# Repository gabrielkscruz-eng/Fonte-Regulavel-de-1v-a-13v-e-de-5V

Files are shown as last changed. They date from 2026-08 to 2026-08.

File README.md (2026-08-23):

# Fonte de Alimentação de Bancada

Projeto de desenvolvimento de **fontes de alimentação para bancada**, realizado no curso de **Engenharia da Computação da Universidade Santa Cecília (UNISANTA)**.

O repositório reúne duas etapas do desenvolvimento:

* **Fonte de alimentação fixa de 5 V**
* **Fonte de alimentação regulável bivolt**

O projeto envolveu o desenvolvimento dos circuitos eletrônicos, criação das placas de circuito impresso, prototipagem, testes e desenvolvimento do encapsulamento da fonte regulável.

---

## Sobre o projeto

Fontes de alimentação são utilizadas para fornecer tensão adequada e estável para circuitos eletrônicos. Em aplicações de bancada, uma fonte regulável permite trabalhar com diferentes níveis de tensão durante testes e desenvolvimento de circuitos.

Neste projeto foram desenvolvidas duas fontes em etapas. A primeira foi uma **fonte fixa de 5 V**, utilizada como uma etapa inicial de desenvolvimento. Posteriormente, foi desenvolvida uma **fonte regulável bivolt**, incorporando uma saída fixa de 5 V e uma saída variável.

O desenvolvimento permitiu aplicar conhecimentos relacionados a **retificação, filtragem, regulagem de tensão, dissipação térmica, proteção de componentes, desenvolvimento de PCB e fabricação do encapsulamento**.

---

# Fonte de 5 V

A primeira etapa do projeto consistiu no desenvolvimento de uma fonte com **saída fixa de 5 V**.

O circuito utiliza o **LM7805** como regulador de tensão e foi desenvolvido utilizando o KiCad.

### Principais características

* Saída regulada de **5 V DC**
* Regulador **LM7805**
* Circuito de retificação
* Filtragem da tensão
* Capacitores para estabilização
* PCB própria

### Fluxo simplificado

```text
Entrada AC
    │
    ▼
Transformação
    │
    ▼
Retificação
    │
    ▼
Filtragem
    │
    ▼
LM7805
    │
    ▼
Saída 5 V DC
```

Os arquivos referentes à fonte fixa estão disponíveis na pasta:

**[`Fonte_5V_Fixa`](./Fonte_5V_Fixa/)**

Nela estão disponíveis os arquivos de projeto do KiCad e os documentos em PDF referentes ao esquemático e à placa.

---

# Fonte Regulável Bivolt

A segunda etapa consistiu no desenvolvimento de uma **fonte de alimentação regulável e bivolt**.

O projeto foi desenvolvido com o objetivo de possuir uma entrada selecionável entre **110 V e 220 V**, uma saída fixa de 5 V e uma saída variável.

O projeto também incluiu o desenvolvimento da PCB, sistema de ventilação e encapsulamento físico.

## Especificações finais

| Característica | Especificação |
| --- | --- |
| Entrada | 110/220 V AC |
| Transformador | 12 V / 3 A |
| Saída fixa | 5 V DC |
| Saída variável | **11 V a 13 V DC** |
| Regulador da saída variável | LM317 |
| Regulador da saída de 5 V | LM7805 |
| Regulador de 12 V | LM7812 |
| Ponte retificadora | KBU808 |
| Potenciômetro | 10 kΩ |
| Dimensão da PCB | 10 × 7,5 cm |
| Dimensão do gabinete | 15 × 11 × 15 cm |
| Material do gabinete | MDF |

A relação de componentes do projeto inclui, entre outros, ponte retificadora KBU808, reguladores LM7805, LM7812 e LM317, diodos 1N4004, capacitores de 4700 µF, capacitores de desacoplamento, resistor de 220 Ω e potenciômetro de 10 kΩ.

---

# Funcionamento

O funcionamento da fonte regulável pode ser dividido em algumas etapas principais:

```text
                 ┌──────────────► LM7805 ───► 5 V DC
                 │
Rede AC          │
  │              │
  ▼              │
Seletor          │
110/220 V        │
  │              │
  ▼              │
Transformador    │
12 V / 3 A       │
  │              │
  ▼              │
KBU808            │
Retificação       │
  │              │
  ▼              │
Filtragem         │
4700 µF           │
  │              │
  ├───────────────┼──────► LM7812 ───► 12 V
  │              │
  │              └──────► LM317 ────► Saída variável
  │                                      │
  ▼                                      ▼
Tensão DC filtrada                    11 V ~ 13 V
```

O transformador reduz a tensão da rede, a ponte KBU808 realiza a retificação e os capacitores fazem a filtragem da tensão. Após essa etapa, os reguladores são responsáveis por gerar as saídas previstas no projeto.

---

# Componentes principais

## Fonte regulável

* Transformador bivolt **12 V / 3 A**
* Ponte retificadora **KBU808**
* **LM7805**
* **LM7812**
* **LM317**
* 3 × diodos **1N4004**
* 2 × capacitores eletrolíticos **4700 µF**
* 2 × capacitores **0,33 µF**
* 3 × capacitores **0,1 µF**
* Resistor **220 Ω**
* Potenciômetro **10 kΩ**
* 6 × conectores borne
* Seletor **110/220 V**
* Chave alavanca
* Fusível
* Conector para cabo de alimentação

---

# Desenvolvimento da PCB

A esquemática e o layout da placa foram desenvolvidos utilizando o **KiCad 7.0**.

A PCB possui dimensões de aproximadamente:

**10 × 7,5 cm**

A fabricação da placa foi realizada por meio de **fresagem em placa de fenolite** nas instalações do **INOVFabLab da Universidade Santa Cecília**.

Os arquivos editáveis do KiCad estão disponíveis diretamente neste repositório, permitindo visualizar e modificar o projeto eletrônico.

### Arquivos disponíveis

```text
Fonte_regulavel/
├── fonte_regulavel.kicad_pro
├── fonte_regulavel.kicad_sch
├── fonte_regulavel.kicad_pcb
├── Esquemática Fonte regulavel.pdf
└── Placa da Fonte Regulavel.pdf
```

---

# Desenvolvimento do encapsulamento

O encapsulamento da fonte regulável foi desenvolvido utilizando o **Autodesk Fusion 360**.

A estrutura foi projetada para acomodar a placa eletrônica e os demais componentes da fonte.

A fabricação foi realizada em **MDF utilizando corte a laser**.

### Dimensões

**15 × 11 × 15 cm**

Foi utilizada uma placa de MDF de 1,3 × 0,9 m para a fabricação do gabinete.

O arquivo do encapsulamento está disponível na pasta:

**[`Gabinete`](./Gabinete/)**

---

# Evolução do projeto

O desenvolvimento da fonte regulável ocorreu a partir da experiência obtida durante a primeira etapa do projeto.

Inicialmente, foi planejada a utilização de duas placas. A placa da entrega parcial possuía saídas fixas de **5 V e 12 V**, sendo a saída de 5 V destinada à carga e a saída de 12 V destinada à ventoinha utilizada para auxiliar no resfriamento do regulador.

Durante a prototipagem foram identificados problemas na placa da entrega parcial. Como consequência, foi decidido integrar os componentes em uma única placa.

Também houve uma alteração no circuito da saída variável. O circuito inicialmente planejado foi substituído pelo **LM317**, devido à praticidade de implementação.

---

# Resultado final

Após a montagem e os testes do protótipo, foram obtidas as seguintes saídas:

### Saída fixa

**5 V DC**

### Saída variável

**11 V a 13 V DC**

A saída variável apresentada neste README corresponde ao **resultado final obtido nos testes do protótipo**.

O relatório acadêmico registra, em sua seção de resultados, uma faixa de 1,10 V a 13 V para o protótipo documentado naquele momento. O valor de **11 V a 13 V** apresentado aqui corresponde ao resultado final considerado para este repositório.

---

# Comparação das duas fontes

| Característica | Fonte 5 V | Fonte Regulável |
| --- | ---: | ---: |
| Saída fixa | 5 V | 5 V |
| Saída variável | Não | 11–13 V |
| Entrada bivolt | Não especificada | 110/220 V |
| LM7805 | Sim | Sim |
| LM7812 | Não | Sim |
| LM317 | Não | Sim |
| PCB | Sim | Sim |
| Encapsulamento | Não | MDF |
| Ventilação | Não | Sim |

---

# Organização do repositório

```text
Fonte-Regulavel-de-1v-a-13v-e-de-5V-main/
│
├── README.md
│
├── Documentação/
│   └── RELATÓRIO FONTE.pdf
│
├── Fonte_5V_Fixa/
│   ├── Esquemática da placa de 5V.pdf
│   ├── Fonte_5v.kicad_pcb
│   ├── Fonte_5v.kicad_pro
│   ├── Fonte_5v.kicad_sch
│   └── Placa de 5V.pdf
│
├── Fonte_regulavel/
│   ├── Esquemática Fonte regulavel.pdf
│   ├── Placa da Fonte Regulavel.pdf
│   ├── fonte_regulavel.kicad_pcb
│   ├── fonte_regulavel.kicad_pro
│   └── fonte_regulavel.kicad_sch
│
└── Gabinete/
    └── Encapsulamento da Fonte regulavel.rld
```

---

# Documentação

O relatório técnico completo do projeto está disponível em formato PDF na pasta **Documentação**.

📄 **[Relatório Técnico](./Documentação/RELATÓRIO%20FONTE.pdf)**

O relatório apresenta:

* Introdução e objetivos;
* Materiais e métodos;
* Desenvolvimento do circuito;
* Desenvolvimento das placas;
* Desenvolvimento do encapsulamento;
* Resultados;
* Conclusão;
* Referências;
* Imagens e registros do projeto.

As **imagens e registros visuais do desenvolvimento e da fonte final estão disponíveis no relatório técnico em PDF**.

Além do relatório, os PDFs de esquemática e layout das placas estão disponíveis nas respectivas pastas dos projetos.

---

# Ferramentas utilizadas

### Projeto eletrônico

* **KiCad 7.0**
* Desenvolvimento de esquemática
* Desenvolvimento de PCB
* Geração dos arquivos de fabricação

### Projeto mecânico

* **Autodesk Fusion 360**
* Modelagem do encapsulamento

### Fabricação

* Fresagem de PCB em placa de fenolite
* Corte a laser de MDF

---

# Objetivos acadêmicos

O projeto teve como objetivo aplicar, de forma prática, conhecimentos adquiridos na disciplina de **Tópicos de Eletrônica**, abrangendo diferentes etapas do desenvolvimento de hardware.

Entre os principais conhecimentos aplicados estão:

* Retificação de tensão;
* Filtragem;
* Regulagem de tensão;
* Utilização de reguladores lineares;
* Dissipação térmica;
* Proteção de componentes;
* Desenvolvimento de PCB;
* Montagem eletrônica;
* Projeto mecânico;
* Fabricação digital;
* Testes e validação de hardware.

O desenvolvimento permitiu compreender na prática as etapas necessárias para transformar um circuito eletrônico em um equipamento físico funcional.

---

# Autores

**Caique Caruso Toscani da Costa**

**Gabriel Kevin Souza Cruz**

**Curso de Engenharia da Computação**
**Universidade Santa Cecília — UNISANTA**

Santos, São Paulo — Brasil
2026

---

# Segurança

> **ATENÇÃO:** este projeto trabalha com tensão de rede elétrica de **110/220 V AC**.

A montagem, manutenção ou reprodução do circuito deve ser realizada com procedimentos adequados de segurança elétrica e por pessoas capacitadas.

Este projeto foi desenvolvido para fins **acadêmicos e educacionais**.

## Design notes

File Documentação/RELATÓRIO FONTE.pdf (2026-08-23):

UNIVERSIDADE SANTA CECÍLIA

CAIQUE CARUSO TOSCANI DA COSTA

GABRIEL KEVIN SOUZA CRUZ

DESENVOLVIMENTO DE UMA FONTE DE ALIMENTAÇÃO REGULÁVEL

BIVOLT

Relatório técnico apresentado à disciplina de Tópicos de Eletrônica do curso de

Engenharia da Computação da Universidade Santa Cecília.

Orientadora: Profª. Raquel Galhardo de Carvalho Lopes

SANTOS

2026

### 1 INTRODUÇÃO

Fontes de alimentação são dispositivos fundamentais em projetos eletrônicos, pois são

responsáveis por converter a energia elétrica da rede em níveis adequados e estáveis para

alimentar circuitos eletrônicos (BOYLESTAD; NASHELSKY, 2013). Em laboratórios,

oficinas e ambientes acadêmicos, as fontes reguláveis possuem grande importância, pois

permitem ajustar a tensão conforme a necessidade de testes e experimentos (USINAINFO,

2023) .

Neste contexto, o presente projeto foi desenvolvido na disciplina de Tópicos de

Eletrônica do curso de Engenharia da Computação, com o objetivo de projetar e construir

uma fonte de alimentação regulável e bivolt, capaz de fornecer tensão contínua estável para

aplicações práticas. O projeto envolveu desde o dimensionamento elétrico até a construção

física, incluindo encapsulamento, ventilação e testes de funcionamento (TONI

ELETRÔNICA, 2024). Como requisito para avaliação o projeto consiste em duas entregas:

uma parcial, que exige uma das saídas funcionais, e outra total, na qual deve conter a

apresentação completa dos itens solicitados.

Além da aplicação prática dos conceitos de eletrônica, o desenvolvimento da fonte de

bancada possibilita aos estudantes compreender etapas importantes do projeto eletrônico,

como regulagem de tensão, dissipação térmica, proteção de componentes e montagem física

do circuito, contribuindo para a formação acadêmica e profissional na área de Engenharia da

Computação (IBYTES, 2023).

### 2 OBJETIVO

Projetar, construir e testar uma fonte de alimentação regulável bivolt, capaz de

fornecer uma saída variável de 0 a 12 V e uma saída fixa de 5V, com corrente mínima de 1 A,

incluindo desenvolvimento do circuito, layout da placa, encapsulamento, sistema de

ventilação e validação prática do funcionamento.

### 3 MATERIAIS E MÉTODOS

Para o desenvolvimento da esquemática do circuito e do layout da placa de circuito

impresso (PCB), utilizou-se o software KiCad (versão 7.0), conforme apresentado na Figura

1 e Figura 2. O projeto consiste em uma placa de 10 × 7,5 cm, a qual utiliza a seguinte

relação de componentes: uma ponte retificadora KBU808 (8 A e 800 V); reguladores de

tensão LM7805, LM7812 e LM317 (variável); três diodos 1N4004; dois capacitores de 4700

µF; dois capacitores de 0,33 µF; três capacitores de 0,1 µF; um resistor de 220 Ω; um

potenciômetro de 10 kΩ; seis conectores bornes; um transformador bivolt (12 V e 3 A); um

seletor de tensão 110/220 V de 6 pinos; uma chave alavanca; um fusível; e um conector

para cabo de alimentação. A prototipagem do circuito foi realizada nas instalações da

prototipadora do INOVFabLab da Universidade Santa Cecília, utilizando o processo de

fresagem em placa de fenolite para a confecção da PCB.

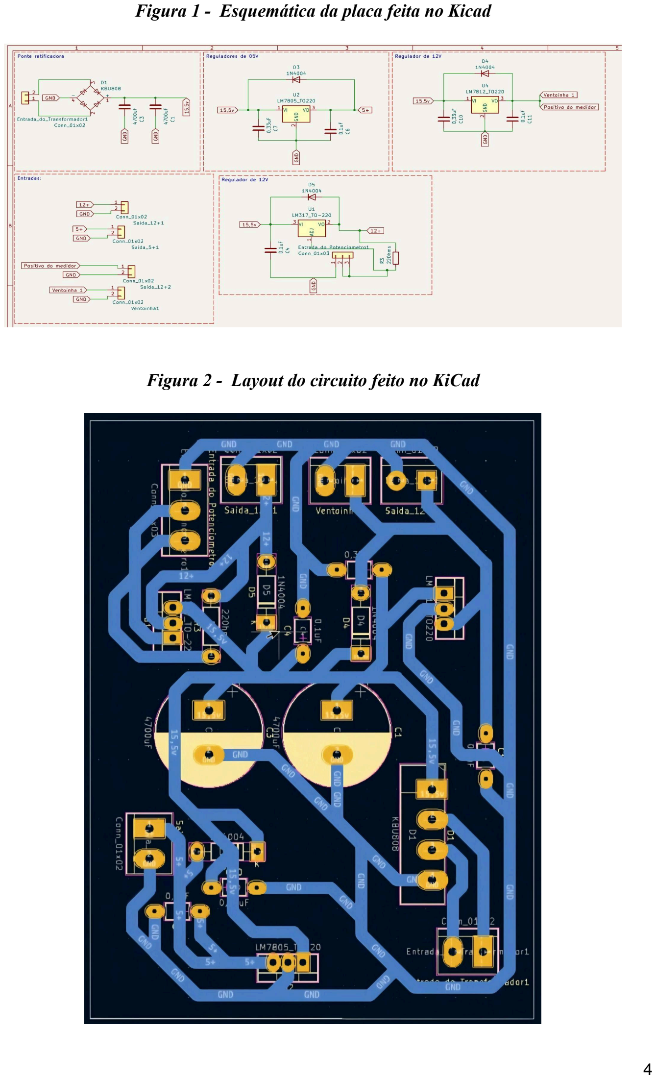
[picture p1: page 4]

Figura 1 - Esquemática da placa feita no Kicad

Figura 2 - Layout do circuito feito no KiCad

O encapsulamento foi projetado no software Autodesk Fusion 360 conforme mostra a

Figura 3. Para sua fabricação, foi utilizada uma placa de MDF de 1,3 × 0,9 m em uma

cortadora a laser do INOVFabLab. O encapsulamento desenvolvido consiste em uma caixa de

MDF com dimensões de 15 × 11 × 15 cm.

Figura 3 - Esboço do encapsulamento feito o Autodesk Fusion 360

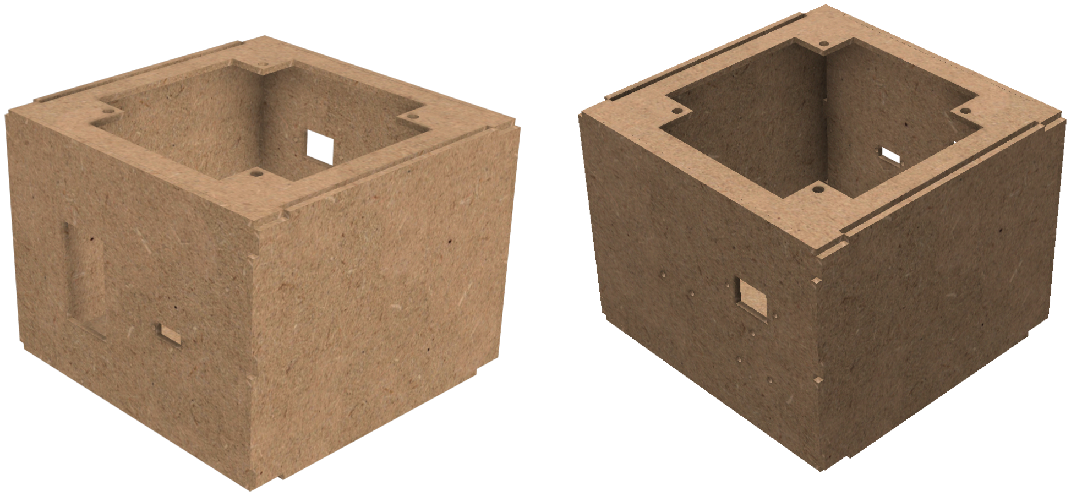
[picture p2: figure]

### 4 DESENVOLVIMENTO

Para o desenvolvimento do projeto inicialmente foi planejado em fazer duas placas

separadas sendo uma da entrega parcial do projeto, que foi prototipado com a saída de 5V e

12V fixa sendo respectivamente uma para carga e outra para ventoinha que é responsável pelo

resfriamento do regulador de 5V. Tendo como componente um trafo de 12V e 3A bivolt, mas

nessa placa sendo utilizado para aceitar 220V, ponte de diodo KBU808, dois capacitores de

4700µF de eletrólitos, para estabilização da energia alternada para energia contínua, 4

capacitores de cerâmica sendo dois de 0,33 µF e os outros dois 0,1 µF, por conta do datasheet

do LM7805 e LM7812 indicar para estabilização da tensão e dois diodos de proteção dos

reguladores. Para entrega final tinha planejado utilizar o circuito de regulador linear que pode

ser visto na figura Figura 4 A , para o regulador variável, mas devido a falhas na prototipagem da placa para entrega parcial, que pode ser visto nas figuras Figura 4 B, houve

mudanças de planos.

Figura 4 - (a) Circuito de regulador linear; (b) Placa da entrega parcial

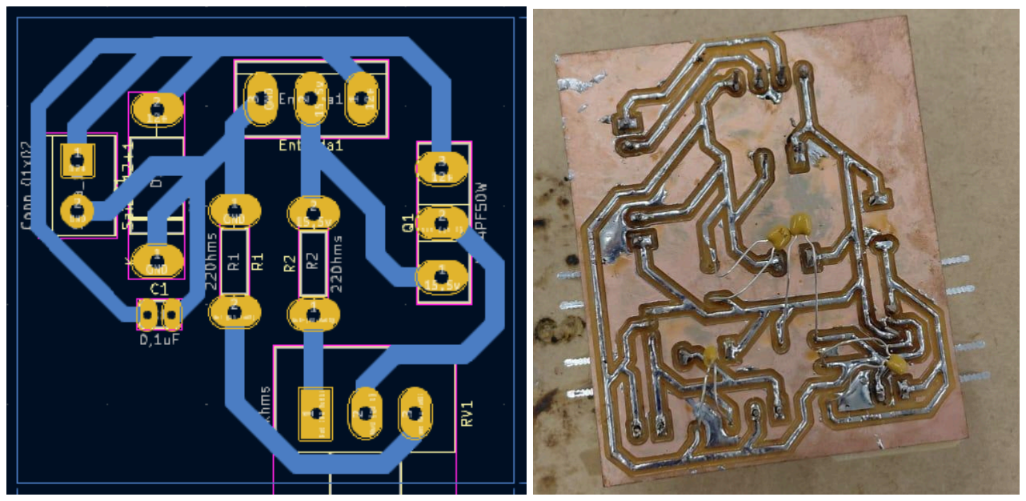
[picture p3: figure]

Devido aos erros da entrega parcial conforme citado anteriormente, decidiu-se montar

uma única placa com os componentes já usados. Alterando, que ao invés de utilizar um

circuito de regulador linear para fonte variável, trocou-se pelo regulador LM317, devido a

praticidade desse C.I, mas em contrapartida esse tipo de regulador não chega a zero sem um

referencial negativo, e devido a essa necessidade a fonte variável ficou de 1,10V a 13V.

Enquanto ao encapsulamento, foi cortado de acordo com planejado sem qualquer problema ou

falha, como pode ser visto na figura 5.

Figura 5 - Imagem da fonte pronta

### 5 RESULTADOS

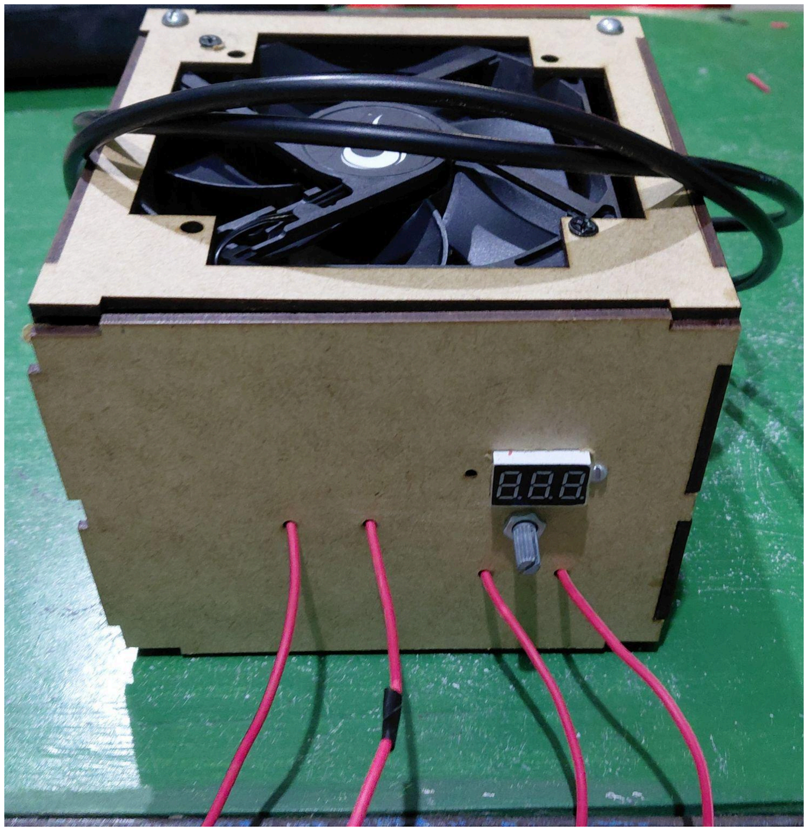
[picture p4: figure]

Após a finalização do protótipo da fonte, obteve-se um resultado razoável, devido ser

exigido para avaliação uma fonte de saída de 5V fixa e outra regulável de 0V à 12V, de no

mínimo de 1A. No entanto, a fonte presente neste relatório apresenta uma saída de 5V fixa,

mas a regulável de 1,10V à 13V, o que pode acabar impactando os testes em laboratório

dependendo do componente e circuito utilizado.

### 6 CONCLUSÃO

O desenvolvimento da fonte de alimentação regulável bivolt permitiu a aplicação

prática dos conhecimentos adquiridos ao longo da disciplina de Tópicos de Eletrônica,

envolvendo etapas de projeto eletrônico, montagem de circuito, desenvolvimento de PCB,

encapsulamento e testes de funcionamento. Durante a execução do projeto, foi possível

compreender na prática conceitos relacionados à retificação, filtragem, regulagem de tensão,

dissipação térmica e proteção de componentes eletrônicos.

Os testes realizados demonstraram a importância do planejamento, da organização dos

componentes e da validação prática durante projetos eletrônicos. Além disso, o

desenvolvimento do encapsulamento em MDF contribuiu para melhorar a estrutura e a

segurança do equipamento. Portanto, conclui-se que o projeto atingiu seus principais

objetivos, proporcionando experiência prática relevante e ampliando os conhecimentos dos

alunos na área de eletrônica e desenvolvimento de hardware.

### 7 REFERÊNCIAS

BOYLESTAD, Robert L.; NASHELSKY, Louis. Dispositivos eletrônicos e teoria de

circuitos. 11. ed. São Paulo: Pearson, 2013.

IBYTES. Fonte regulável 3A com transistor 2N3055 para bancada. 2023. Disponível em:

https://www.ibytes.com.br/fonte-regulavel-3a-2n3055-projeto-bancada/. Acesso em: 24 maio

2026.

TONI ELETRÔNICA. Projeto prático de fonte de alimentação DC utilizando LM317 e

LM1117. 2024. Disponível em:

https://te1.com.br/2024/07/lm317-lm1117-design-pratico-fonte-alimentacao-dc/. Acesso em:

24 maio 2026.

USINAINFO. Fonte de bancada e sua importância em projetos eletrônicos. 2023. Disponível

em: https://www.usinainfo.com.br/fonte-de-bancada-71. Acesso em: 24 maio 2026.

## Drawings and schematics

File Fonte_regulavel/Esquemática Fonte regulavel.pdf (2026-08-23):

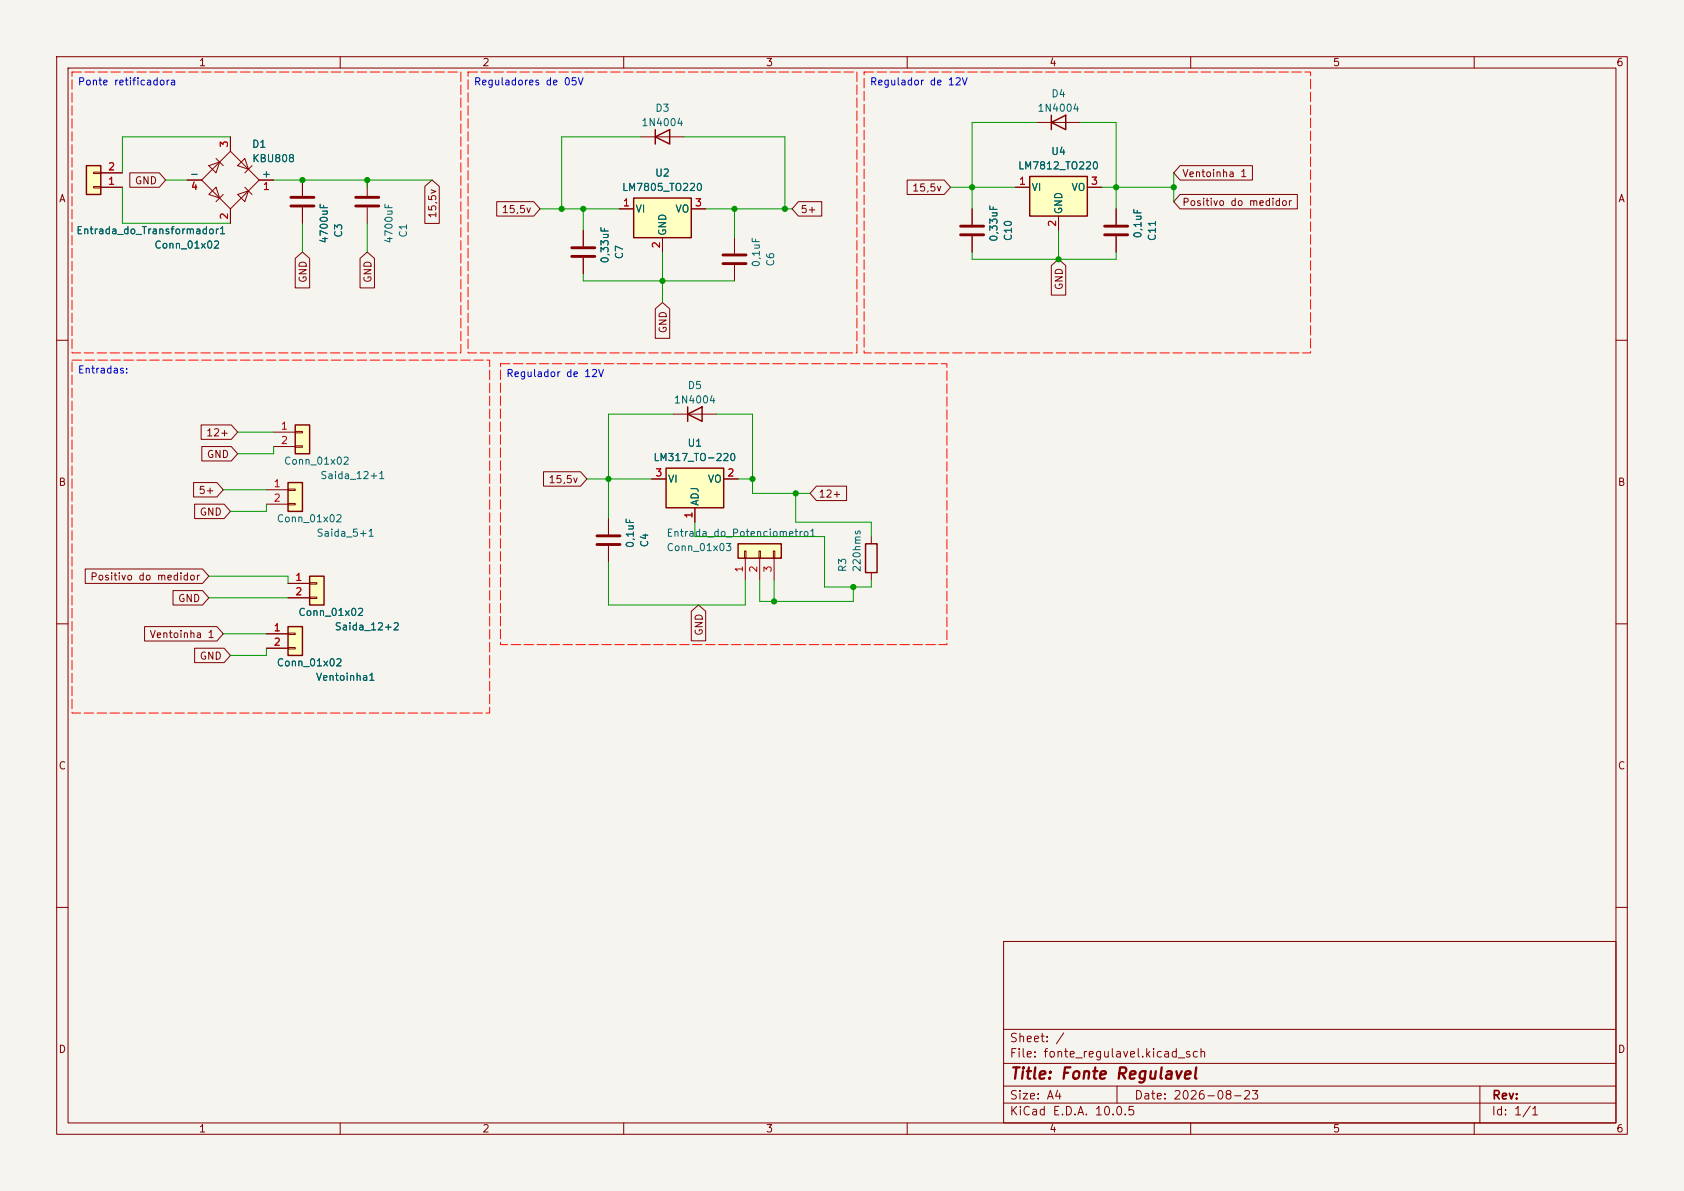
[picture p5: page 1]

Ventoinha 1 Positivo do medidor Positivo do medidorGND

Size: A4 | Rev:
KiCad E.D.A. 10.0.5 | Id: 1/1

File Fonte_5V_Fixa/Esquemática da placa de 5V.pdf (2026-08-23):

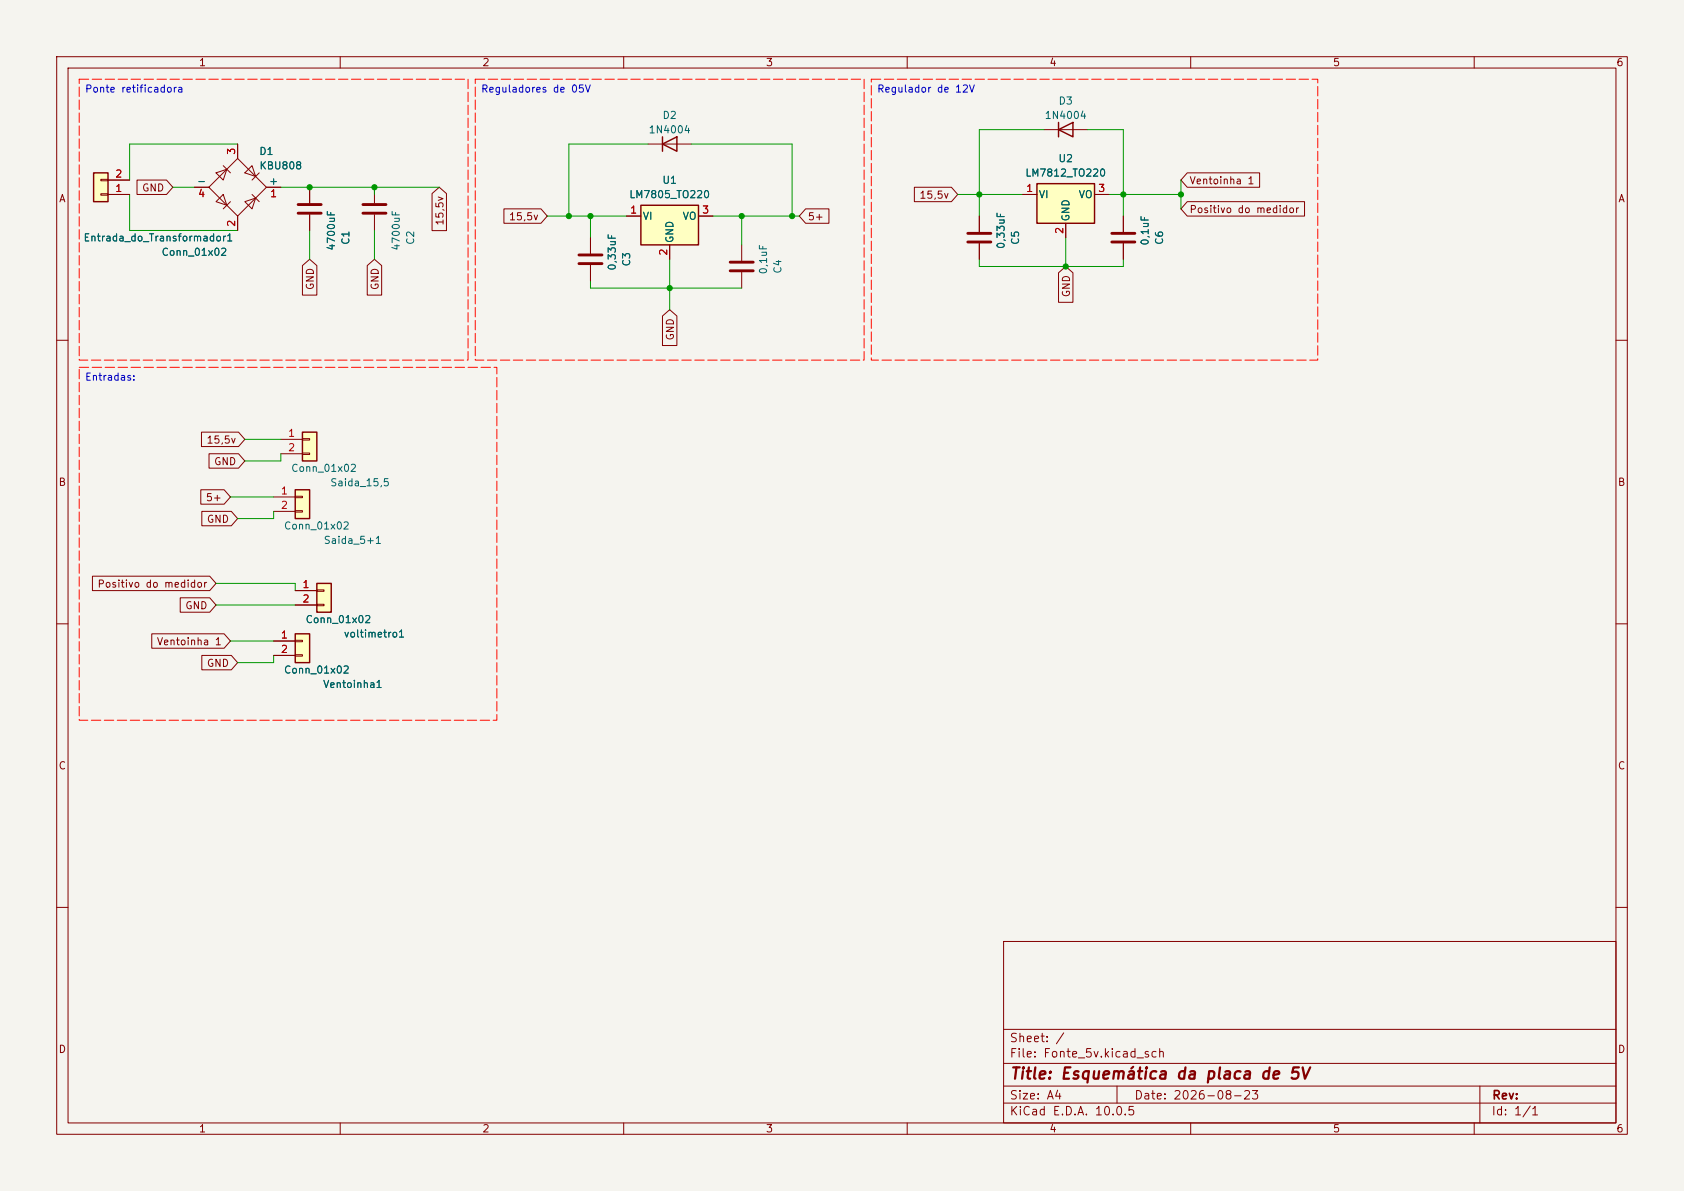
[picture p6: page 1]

Positivo do medidor GND

Sheet: /
File: Fonte_5v.kicad_sch
Title: Esquemática da placa de 5V

Size: A4 | Rev:
KiCad E.D.A. 10.0.5 | Id: 1/1

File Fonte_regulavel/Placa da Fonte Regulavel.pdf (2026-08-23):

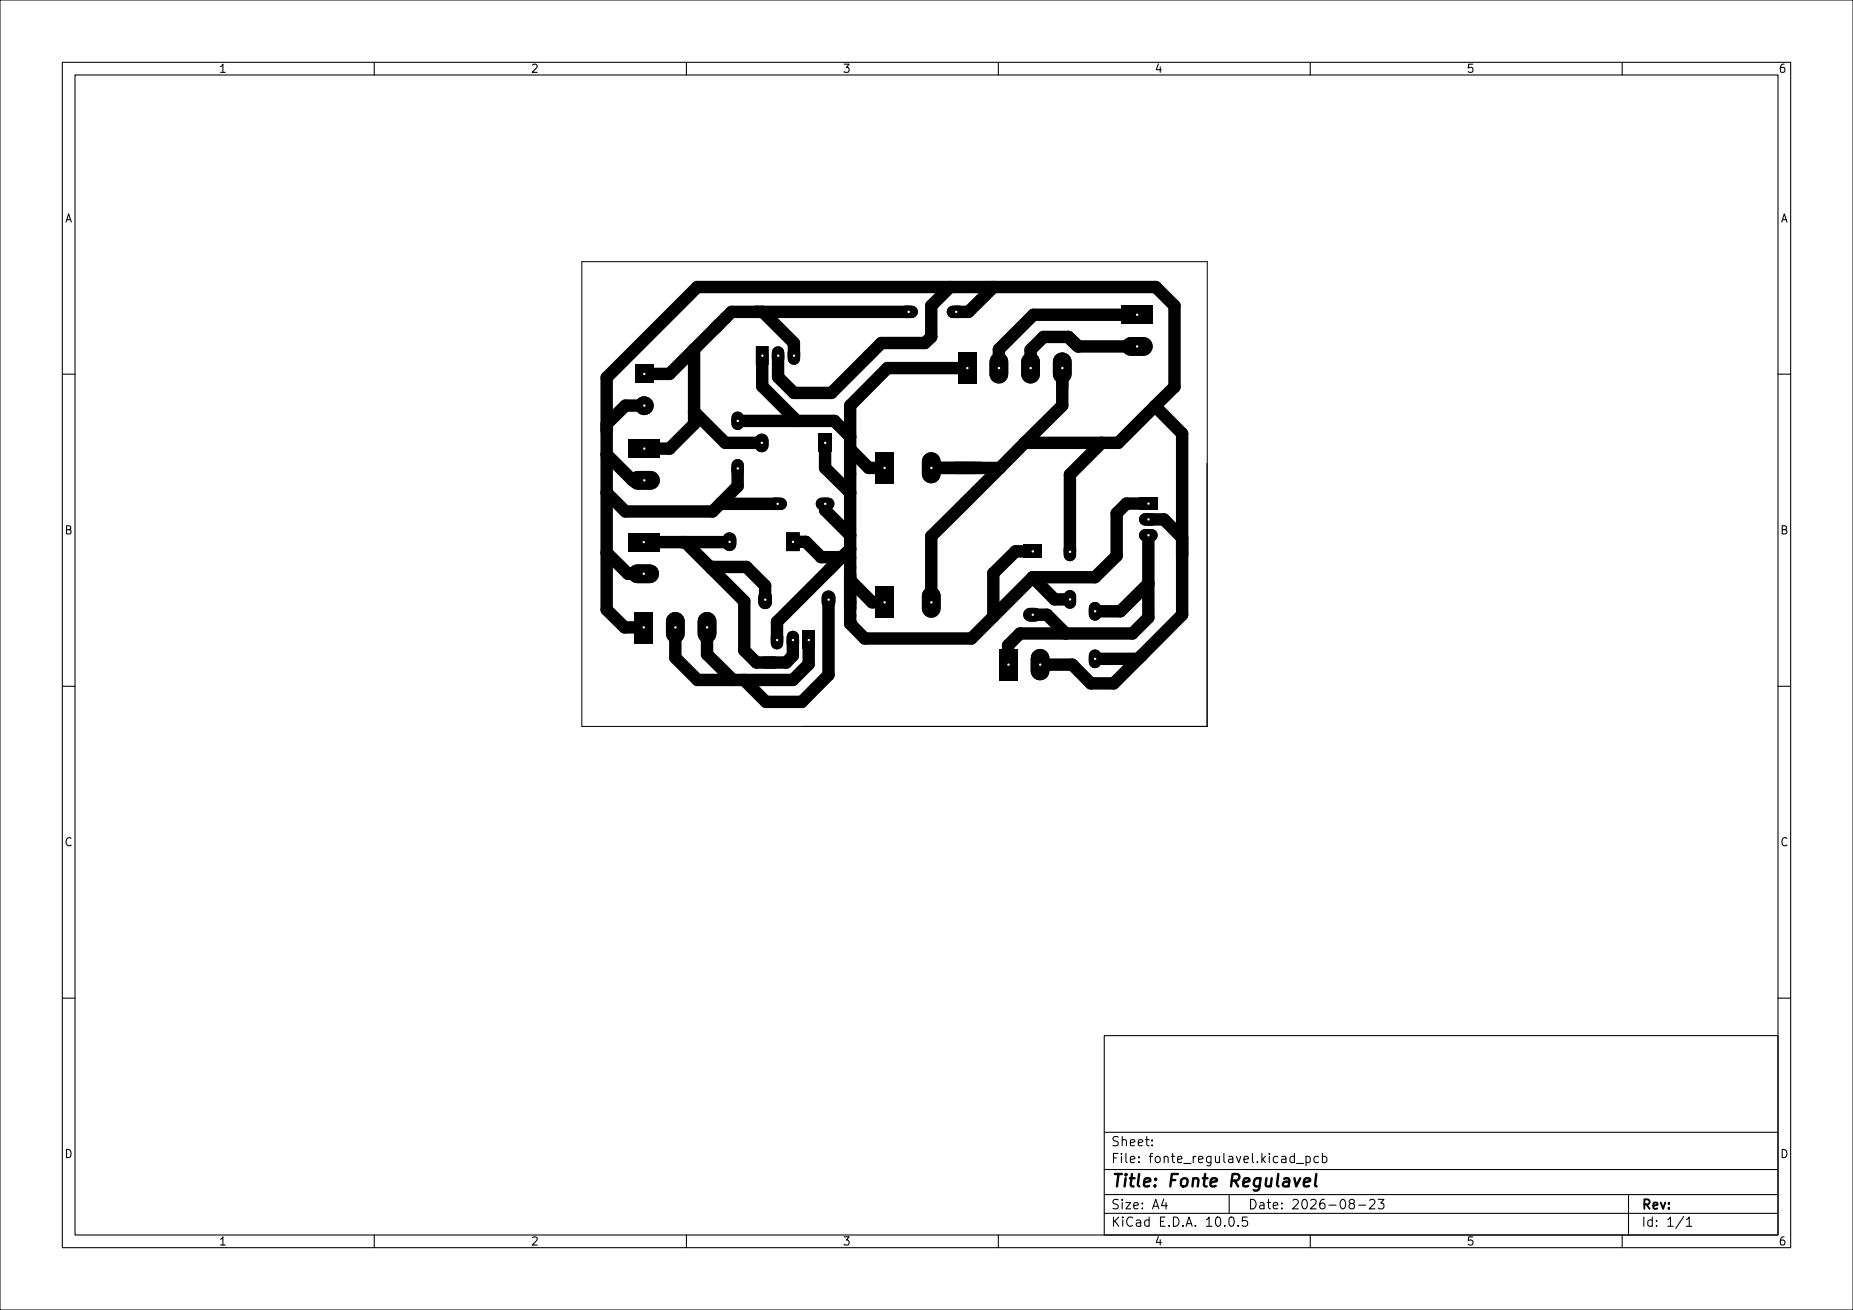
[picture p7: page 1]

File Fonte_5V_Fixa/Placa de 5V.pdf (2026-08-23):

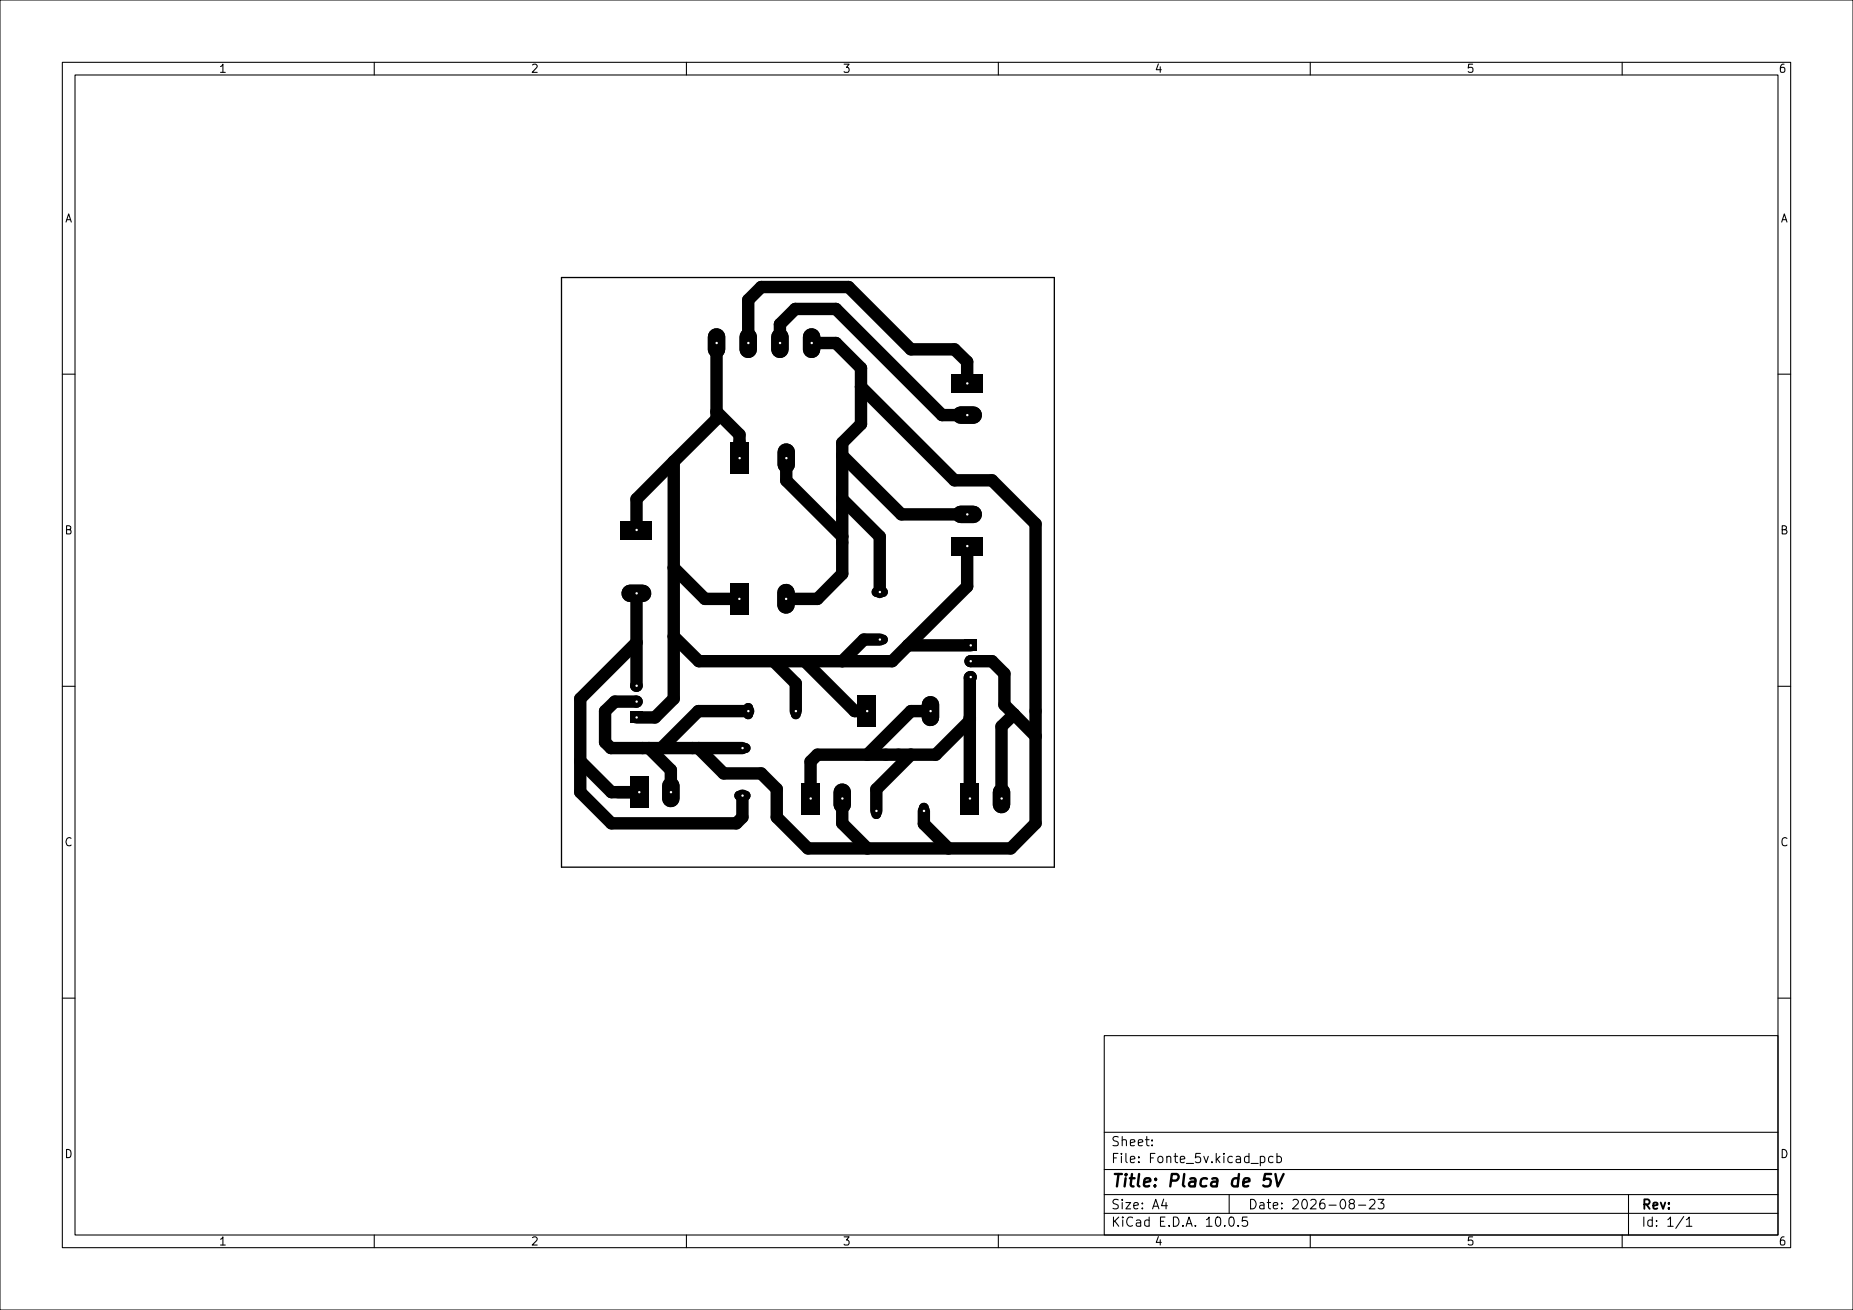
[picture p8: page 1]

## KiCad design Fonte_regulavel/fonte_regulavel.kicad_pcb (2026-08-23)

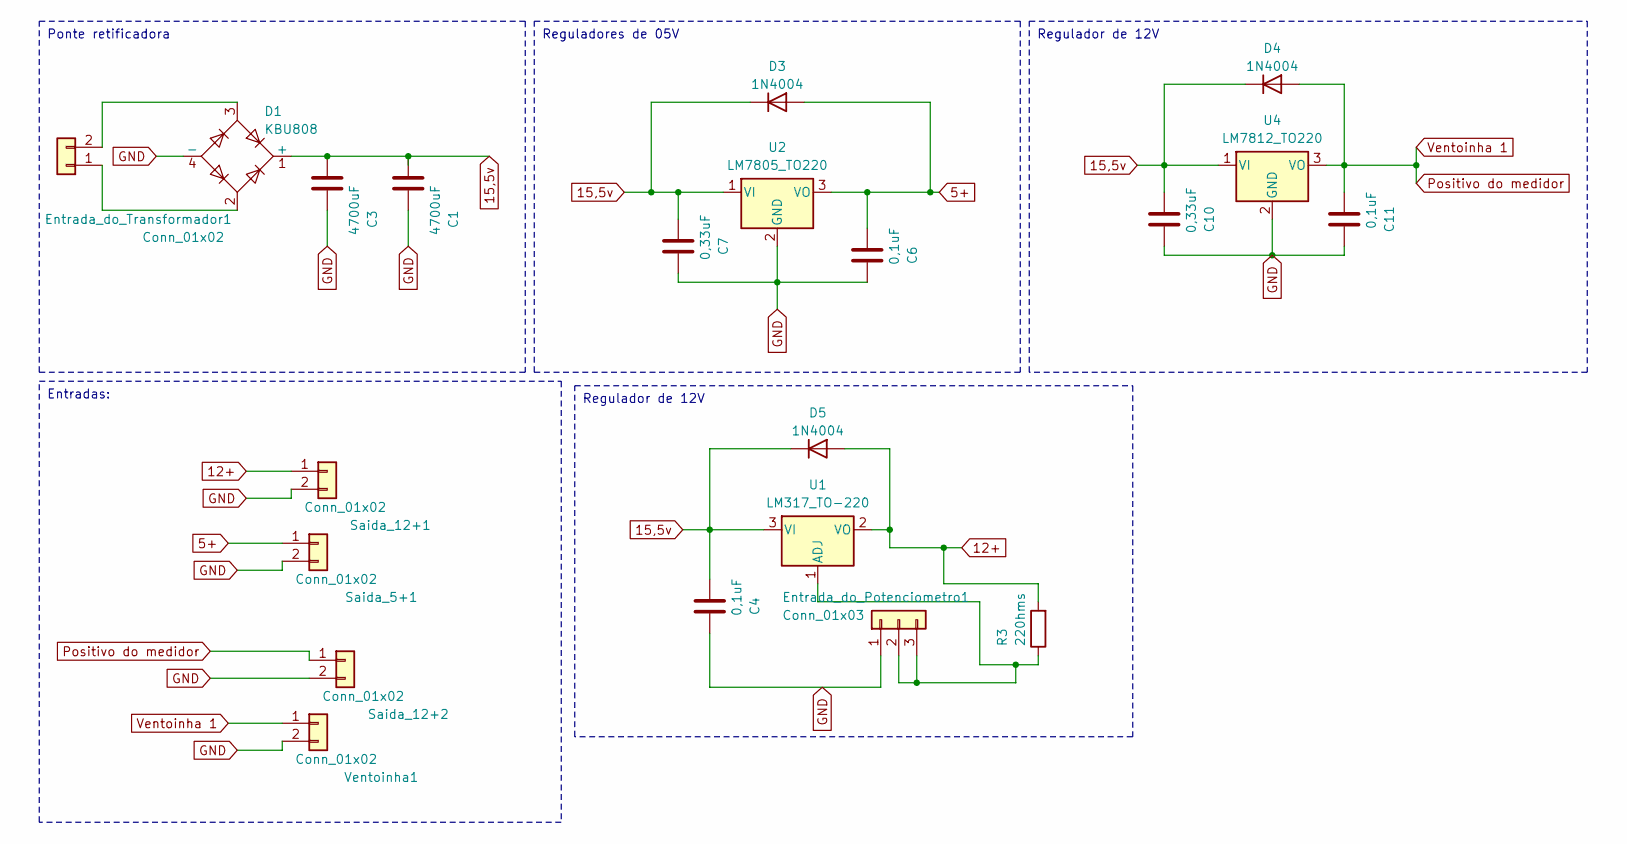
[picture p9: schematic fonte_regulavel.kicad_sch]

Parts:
C1, C3: 4700uF; CP_Radial_D18.0mm_P7.50mm
C4, C6, C11: 0,1uF; C_Disc_D3.8mm_W2.6mm_P2.50mm
C7, C10: 0,33uF; C_Disc_D3.8mm_W2.6mm_P2.50mm
D1: KBU808; Diode_Bridge_Vishay_KBU
D3, D4, D5: 1N4004; D_DO-41_SOD81_P10.16mm_Horizontal
Entrada_do_Potenciometro1: Conn_01x03; TerminalBlock_bornier-3_P5.08mm
Entrada_do_Transformador1: Conn_01x02; TerminalBlock_bornier-2_P5.08mm
R3: 220hms; R_Axial_DIN0207_L6.3mm_D2.5mm_P10.16mm_Horizontal
Saida_5+1, Saida_12+1, Saida_12+2: Conn_01x02; TerminalBlock_bornier-2_P5.08mm
U1: LM317_TO-220; TO-220-3_Vertical
U2: LM7805_TO220; TO-220-3_Vertical
U4: LM7812_TO220; TO-220-3_Vertical
Ventoinha1: Conn_01x02; TerminalBlock_bornier-2_P5.08mm

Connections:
5+: C6.1, D3.2 (A), Saida_5+1.1, U2.3 (VO)
12+: D5.2 (A), R3.2, Saida_12+1.1, U1.2 (VO)
15,5v: C1.1, C3.1, C4.1, C7.1, C10.1, D1.1 (+), D3.1 (K), D4.1 (K), D5.1 (K), U1.3 (VI), U2.1 (VI), U4.1 (VI)
GND: C1.2, C3.2, C4.2, C6.2, C7.2, C10.2, C11.2, D1.4 (-), Entrada_do_Potenciometro1.1, Saida_5+1.2, Saida_12+1.2, Saida_12+2.2, U2.2 (GND), U4.2 (GND), Ventoinha1.2
unnamed: Entrada_do_Potenciometro1.2, Entrada_do_Potenciometro1.3, R3.1, U1.1 (ADJ)
unnamed: D1.2, Entrada_do_Transformador1.1
unnamed: D1.3, Entrada_do_Transformador1.2
Positivo do medidor: C11.1, D4.2 (A), Saida_12+2.1, U4.3 (VO), Ventoinha1.1

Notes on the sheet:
Regulador de 12V
Reguladores de 05V
Entradas:
Ponte retificadora

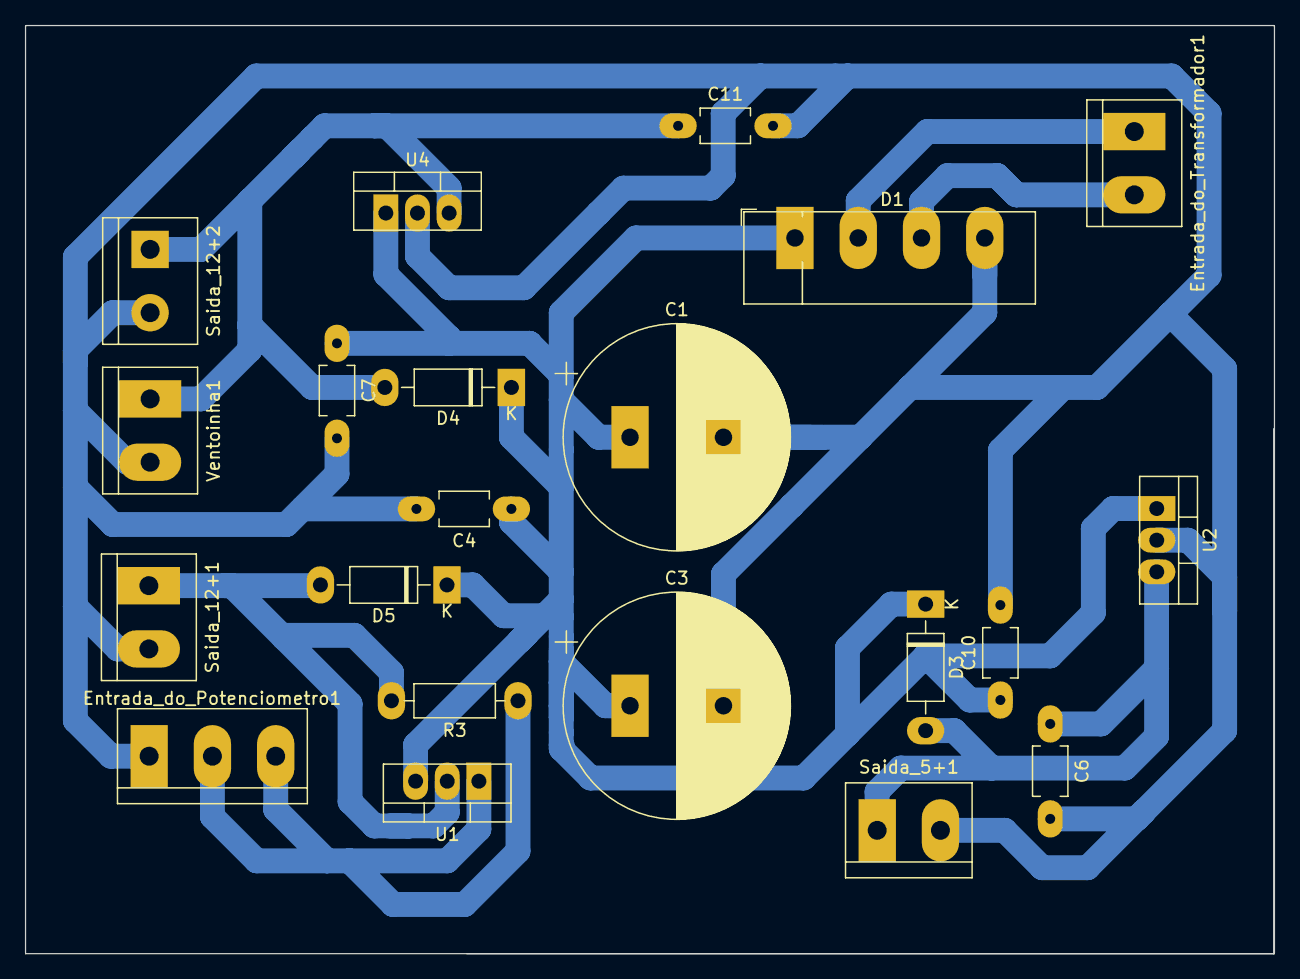
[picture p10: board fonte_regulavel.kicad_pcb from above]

Board: 2 copper layers, 100.2 x 74.5 mm, 21 parts (0 on the bottom side), 8 nets.

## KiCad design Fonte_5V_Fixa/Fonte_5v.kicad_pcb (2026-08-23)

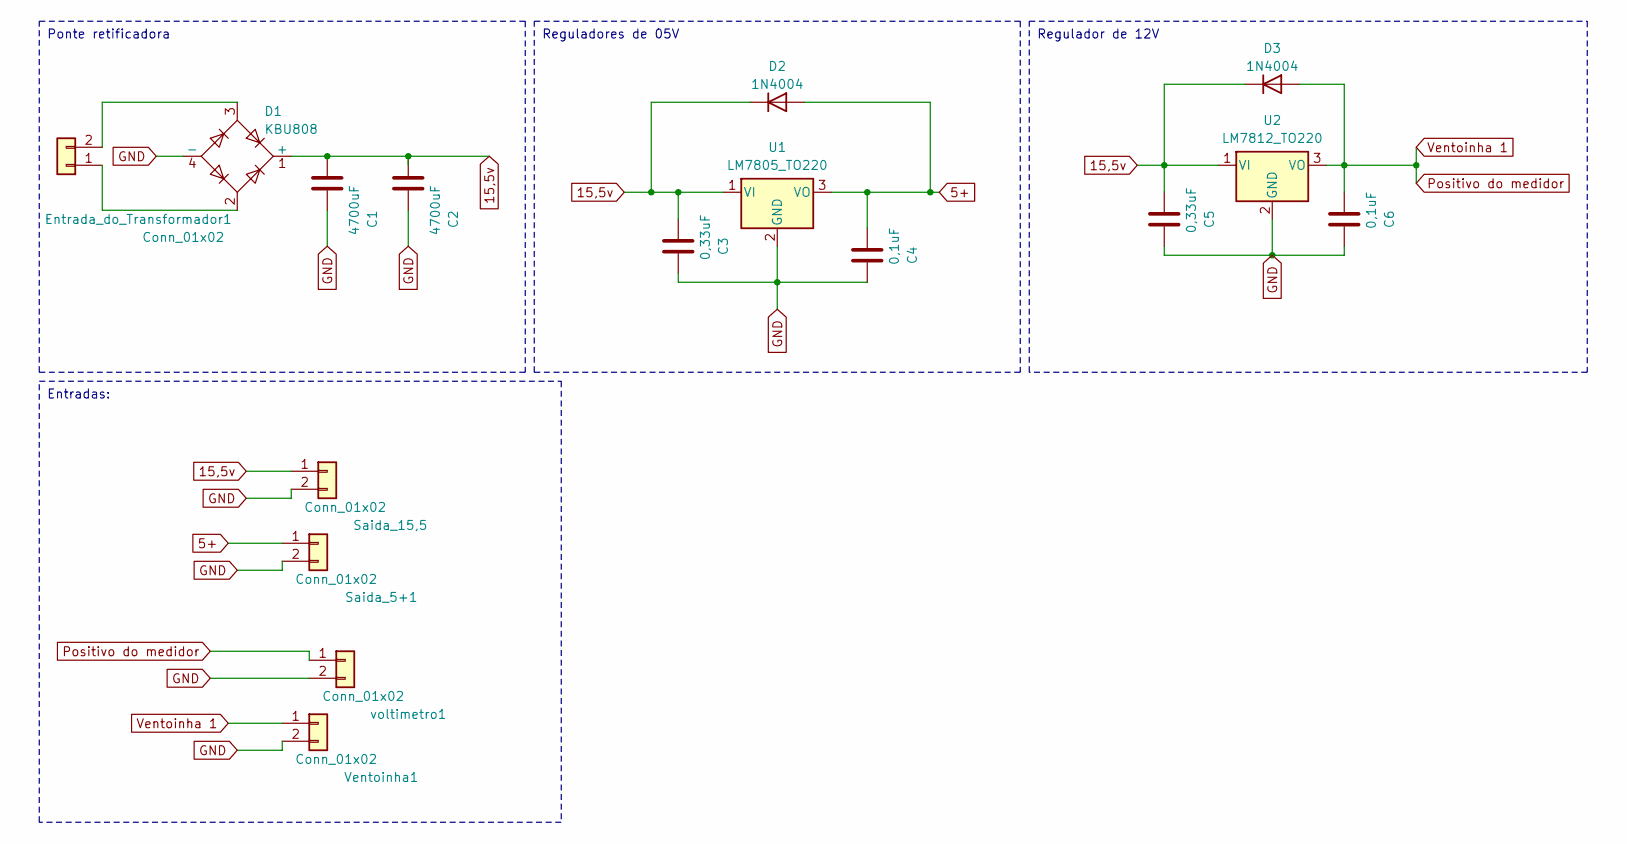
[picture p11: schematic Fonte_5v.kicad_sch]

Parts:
C1, C2: 4700uF; CP_Radial_D18.0mm_P7.50mm
C3, C5: 0,33uF; C_Disc_D3.8mm_W2.6mm_P2.50mm
C4, C6: 0,1uF; C_Disc_D3.8mm_W2.6mm_P2.50mm
D1: KBU808; Diode_Bridge_Vishay_KBU
D2, D3: 1N4004; D_DO-41_SOD81_P10.16mm_Horizontal
Entrada_do_Transformador1: Conn_01x02; TerminalBlock_bornier-2_P5.08mm
Saida_5+1, Saida_15,5: Conn_01x02; TerminalBlock_bornier-2_P5.08mm
U1: LM7805_TO220; TO-220-3_Vertical
U2: LM7812_TO220; TO-220-3_Vertical
Ventoinha1: Conn_01x02; TerminalBlock_bornier-2_P5.08mm
voltimetro1: Conn_01x02; TerminalBlock_bornier-2_P5.08mm

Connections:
5+: C4.1, D2.2 (A), Saida_5+1.1, U1.3 (VO)
15,5v: C1.1, C2.1, C3.1, C5.1, D1.1 (+), D2.1 (K), D3.1 (K), Saida_15,5.1, U1.1 (VI), U2.1 (VI)
GND: C1.2, C2.2, C3.2, C4.2, C5.2, C6.2, D1.4 (-), Saida_5+1.2, Saida_15,5.2, U1.2 (GND), U2.2 (GND), Ventoinha1.2, voltimetro1.2
unnamed: D1.2, Entrada_do_Transformador1.1
unnamed: D1.3, Entrada_do_Transformador1.2
Positivo do medidor: C6.1, D3.2 (A), U2.3 (VO), Ventoinha1.1, voltimetro1.1

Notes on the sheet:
Entradas:
Reguladores de 05V
Regulador de 12V
Ponte retificadora

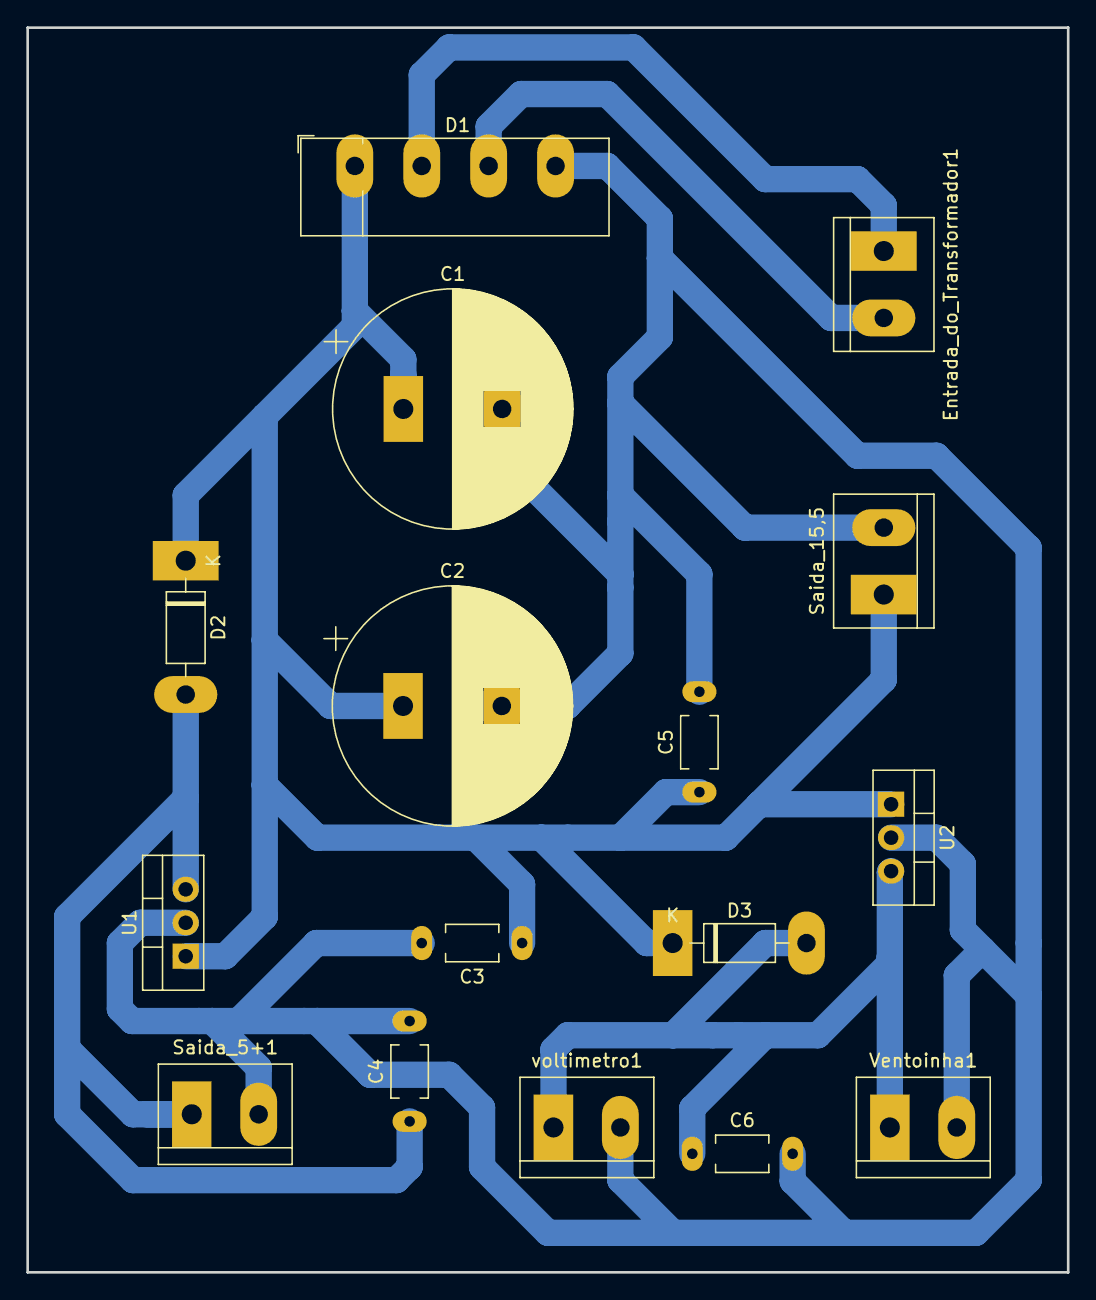
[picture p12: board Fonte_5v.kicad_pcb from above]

Board: 2 copper layers, 79.0 x 94.5 mm, 16 parts (0 on the bottom side), 6 nets.

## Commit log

2026-08-23 Add files via upload
    Adicionando os arquivos das placas, e do encapsulamento.
    [Fonte_5v.kicad_pcb, Fonte_5v.kicad_sch, fonte_regulavel.kicad_pcb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]
2026-08-23 Revise README for bench power supply project
    Updated the README to reflect project details and structure for bench power supplies developed during academic coursework.
